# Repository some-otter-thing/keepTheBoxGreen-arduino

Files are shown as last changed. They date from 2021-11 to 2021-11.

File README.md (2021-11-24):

### Table of contents

- [Project Description](#project-description)
- [Data Flow](#data-flow)
- [Local Installation](#local-installation)
- [Schematics & blueprint](#schematics-and-blueprint)
- [Hardware Components](#hardware-components)

### Project Description

The main goal is to build an Arduino device, which is going to collect data from different sensors. It has simple logic behind which helps to indicate if any working conditions are violated by changing the colour of a box #keepTheBoxGreen. For example when a person is sitting in front of the laptop for more than 45 min, the light of the box will change its colour to red and LCD display will print an appropriate advice, in case if any sensors metrics will be out of the optimal numbers, LCD display will show that by changing color of the displayed data.

This repo consists of code for Arduino MKR1010 board.

API implementation repo: [link to api repo](https://github.com/some-otter-thing/keepTheBoxGreen-api) 

WEB implementation repo: [link to web repo](https://github.com/some-otter-thing/keepTheBoxGreen-fe) 

Prototypes:
<div display="flex">
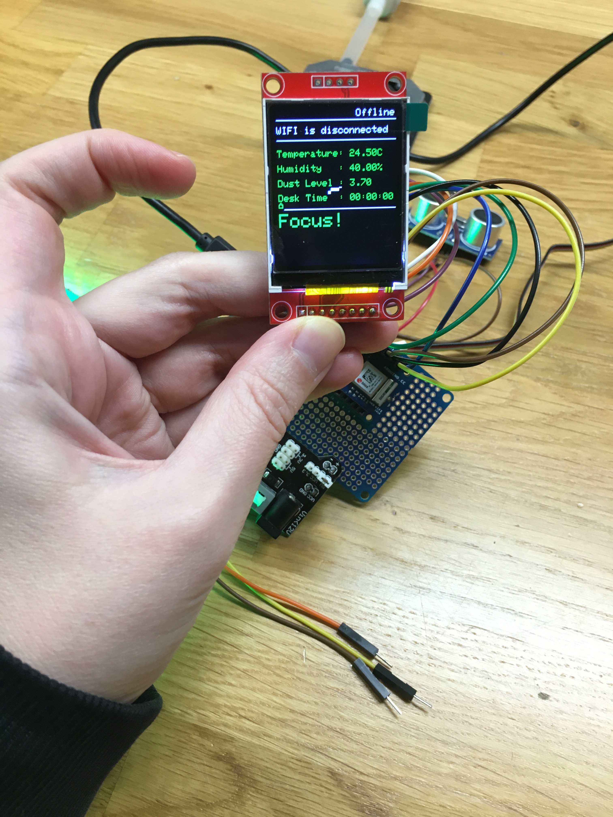
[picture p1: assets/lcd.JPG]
lcd
  
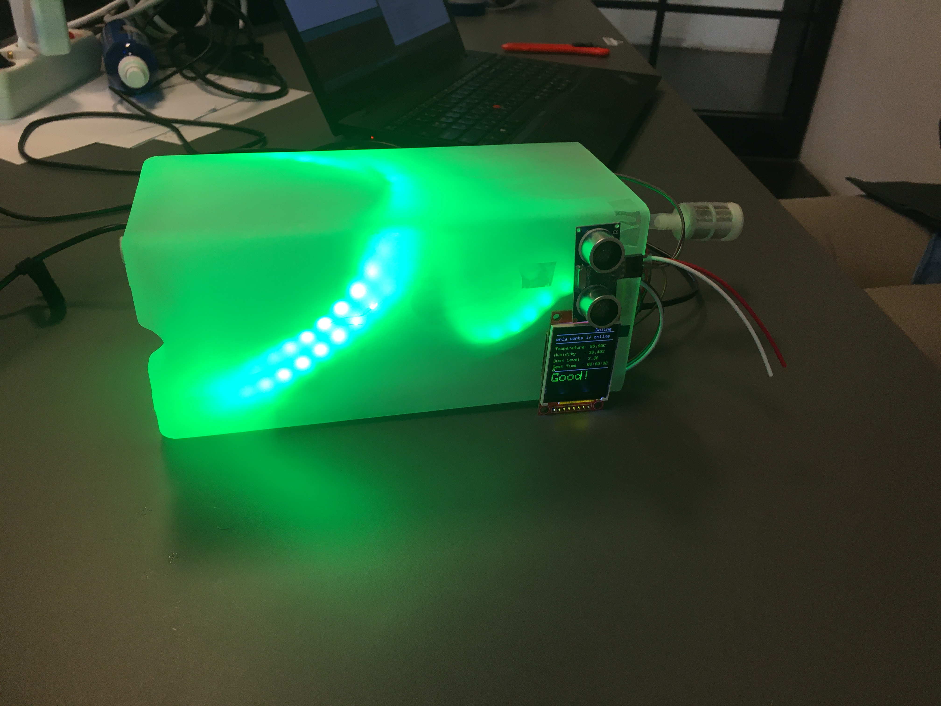
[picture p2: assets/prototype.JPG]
prototype
  
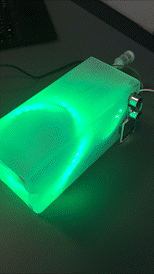
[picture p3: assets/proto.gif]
  
</div>

### Data Flow
The board uses Azure cloud provider for publishing and storing data.

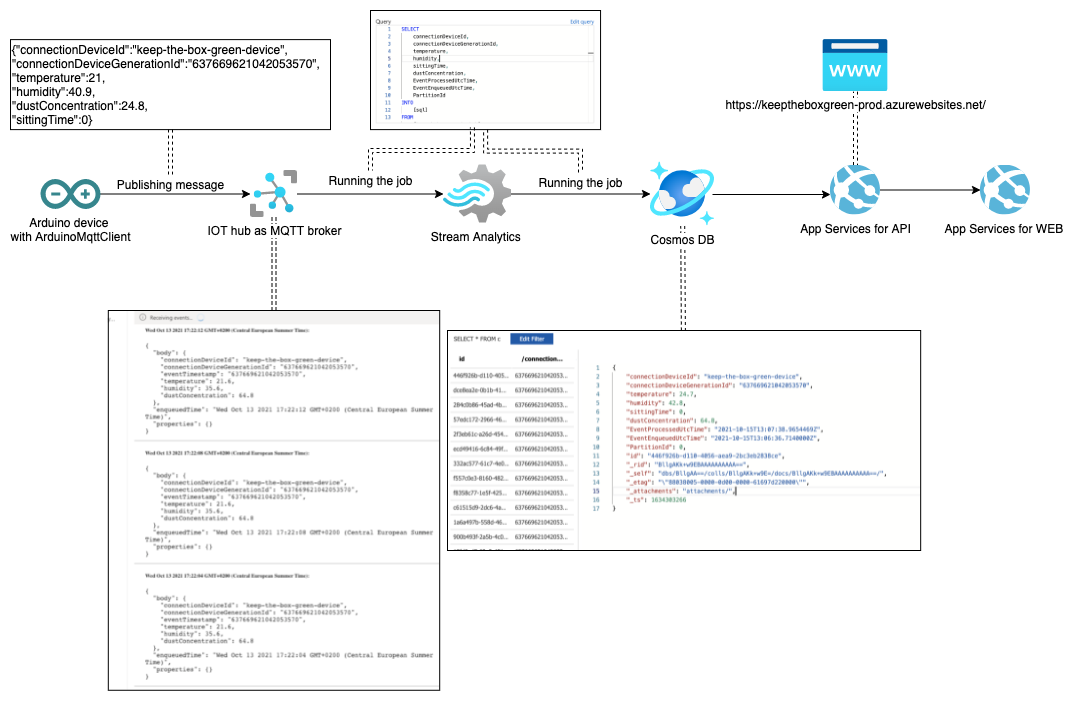
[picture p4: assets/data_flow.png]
data-flow

### Local Installation:

1. Create a header file within Main folder

```
touch arduino_secrets.h
```

2. Add information about wifi:

```
#define SECRET_SSID "here is network name"
#define SECRET_PASS "here is the password of wifi"
#define SECRET_BROKER    ""
#define SECRET_DEVICE_ID ""
```
3. You need to have following libraries installed:

   1. Wifi:
      - WiFiNINA library
   2. MQTT connection:
      - ArduinoMqttClient
      - ArduinoBearSSL
      - ArduinoECCX08
      - ArduinoJson
   3. TFT Display
      - Adafruit BusIO 
      - Adafruit_GFX
      - Adafruit_ST7735 & ST7798
   4. DHT22
      - Adafruit DHT sensor library
   5. LED
      - FastLED
   6. Dust Sensor
      - Nova Fitness SDS dust sensors library
### Guides:

- Connecting to wifi - <a href="https://www.arduino.cc/en/Guide/MKRWiFi1010/connecting-to-wifi-network">link</a>

- Explanation of necessary drivers for the Arduino MKR1000 series of boards - <a href="https://www.arduino.cc/en/Guide/MKR1000">link</a>

- Helper to make json https://arduinojson.org/v6/assistant/

### Schematics and blueprint

- Use [fritzing](https://fritzing.org/) to open the file in assets folder
- Need to sign up if you don't want to pay for it..

### Hardware Components:

1. Arduino MKR 1010 Board
2. DHT22 Sensor
3. HC-SR0 4Ultrasonic Sensor
4. Generic LED Strip
5. Generic 1.8" TFT Display
6. Nova PM SDS011 PM 2.5 sensor

Fritzing breadboard hardware planning
Fritzing schematics planning

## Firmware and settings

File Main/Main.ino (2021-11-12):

#include <ArduinoBearSSL.h>
#include <ArduinoECCX08.h>
#include <ArduinoMqttClient.h>
#include <ArduinoJson.h>
#include <utility/ECCX08SelfSignedCert.h>

#include <WiFiNINA.h>

#include "arduino_secrets.h"
#include "display_constants.h"
#include "main_constants.h"
#include "sitting_time_constants.h"
#include <DHT.h>
#include <FastLED.h>

// importing display lib
#include <Adafruit_GFX.h>    // Core graphics library
#include <Adafruit_ST7735.h> // Hardware-specific library for ST7735
#include <Adafruit_ST7789.h> // Hardware-specific library for ST7789
#include <SPI.h>

// dust sensor
#include "SdsDustSensor.h"

// wifi
WiFiClient wifiClient;               // Used for the TCP socket connection
BearSSLClient sslClient(wifiClient); // Used for SSL/TLS connection
MqttClient mqttClient(sslClient);

char ssid[] = SECRET_SSID;
char pass[] = SECRET_PASS;
const char broker[] = SECRET_BROKER;
String deviceId = SECRET_DEVICE_ID;

int status = WL_IDLE_STATUS;
int wifiRetries = 0;
int mqttRetries = 0;
unsigned long timeWIFISetUpAttempt;
// interfacing hum/temp sensor pins
DHT dht(DHTPIN, DHTTYPE);

CRGB leds[NUM_LEDS];
// interfacing display lib pins
Adafruit_ST7735 tft = Adafruit_ST7735(TFT_CS, TFT_DC, TFT_RST);

// dust sensor
SdsDustSensor sds(Serial1);

void setup() {
  Serial.begin(9600);

  // display
  setupDisplay();

  // wifi connect try for MAX_WIFI_RETRIES times
  while (status != WL_CONNECTED && (wifiRetries < MAX_WIFI_RETRIES)) {
    setupWIFI();
    displayWIFIAttempts();
    timeWIFISetUpAttempt = millis(); // used to check wifi connection
  }
  if (status == WL_CONNECTED) {
    Serial.println("You're connected to the network");
    printWiFiData();
    wifiRetries = 0;
  }
  // mqtt
  setupMQTT();

  // temperature and humdity
  dht.begin();
  // ultrasonic
  pinMode(trigPin, OUTPUT);
  pinMode(echoPin, INPUT);

  // LEDs
  FastLED.addLeds<WS2812, LED_PIN, GRB>(leds, NUM_LEDS);
  FastLED.setBrightness(BRIGHTNESS);

  // dust sensor
  setupDust();
}

void loop() {
  unsigned long currentTime =
    millis();                 // set up current time to arduino running time
  unsigned long lastMillis = 0; // used for mqtt connection


  if (WiFi.status() != WL_CONNECTED && (millis() - timeWIFISetUpAttempt) > 1800000) {
    wifiRetries = 0;
    connectWiFi();
    timeWIFISetUpAttempt =   millis();
  }
  // TODO: Implement same retry logic as for wifi 
  if (!mqttClient.connected() && WiFi.status() == WL_CONNECTED) {
    connectMQTT();
    // poll for new MQTT messages and send keep alives
    mqttClient.poll();
  }

  digitalWrite(trigPin, LOW);
  delay(500);
  digitalWrite(trigPin, HIGH);
  delay(500);
  digitalWrite(trigPin, LOW);

  duration = pulseIn(
               echoPin, HIGH); // returns the sound wave travel time in microseconds
  distance =
    duration * 0.034 / 2; // speed of sound wave divided by 2 (go and back)

  temp = dht.readTemperature();
  hum = dht.readHumidity();
  PmResult pm = sds.readPm();
  dust = pm.pm25;

  sittingTimeColor = getSittingTimeColor(distance, currentTime);
  tempColor = getTempColor(temp);
  humColor = getHumColor(hum);
  dustColor = getDustColor(dust);
  dustMessage = getDustMessage();
  timeSitting = getSittingTime(distance, currentTime);

  // publish a message every 10 seconds.
  if (millis() - lastMillis > 10000) {
    lastMillis = millis();
    publishMessage();
  }

  if (sittingTimeColor == GREEN)
  {
    for (int i = 0; i < NUM_LEDS; i++)
    {
      leds[i] = CRGB(0, 255, 0);
      FastLED.show();
    }
  }
  else if (sittingTimeColor == RED)
  {
    for (int i = 0; i < NUM_LEDS; i++)
    {
      leds[i] = CRGB(255, 0, 0);
      FastLED.show();
    }
  }
  else if (sittingTimeColor == YELLOW)
  {
    for (int i = 0; i < NUM_LEDS; i++)
    {
      leds[i] = CRGB(255, 255, 0);
      FastLED.show();
    }
  }

  // display
  displayValue();

  // delay(1000);
}

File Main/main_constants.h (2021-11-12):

char* sittingTimeColor = "GREEN";
char* tempColor = "GREEN";
char* humColor = "GREEN";
char* dustColor = "GREEN";
char* dustMessage = "";

char* GREEN = "GREEN";
char* YELLOW = "YELLOW";
char* RED = "RED";

// ultrasonic sensor
#define echoPin   5
#define trigPin   0

// led
#define LED_PIN 4
#define NUM_LEDS 100
#define BRIGHTNESS 50

// dht22
#define DHTPIN    1
#define DHTTYPE DHT22

// display 
#define TFT_CS   6
#define TFT_RST -1
#define TFT_DC   7
#define TFT_SCLK 9
#define TFT_MOSI 8

long duration;
int distance;
float hum;
float temp;
float dust;

// wifi

#define MAX_WIFI_RETRIES 2
#define MAX_MQTT_RETRIES 2

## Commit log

2021-10-08 Clean up comments to avoid conflicts
    [Main.ino]
2021-10-09 Utrasonic sensor logic
2021-10-10 Printing sitting time
2021-10-10 add temperature logic
2021-10-13 Implement led strip
2021-10-17 added readme and blueprint file
    [greenbox.fzz]
2021-10-20 printing hh:mm:ss on display
2021-10-21 added dust sensor/library on readme
2021-10-21 changed library for samd board
2021-10-21 dust sensor init
2021-10-21 wip: dust sensor display
2021-10-21 updated fritzing
    [greenbox.fzz]
2021-10-23 use dust color in the led logic
2021-10-25 changed led constant
2021-10-25 uncommented message broker part
    [Main.ino]
2021-10-25 changed dir name of fritzing related stuff
    [greenbox.fzz]
2021-10-25 added schematics
2021-11-12 Change the logic of led color
